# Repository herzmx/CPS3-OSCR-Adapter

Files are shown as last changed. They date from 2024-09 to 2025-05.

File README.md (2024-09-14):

# CPS3 SIMM/CARTRIDGE PORT ADAPTER for OSCR

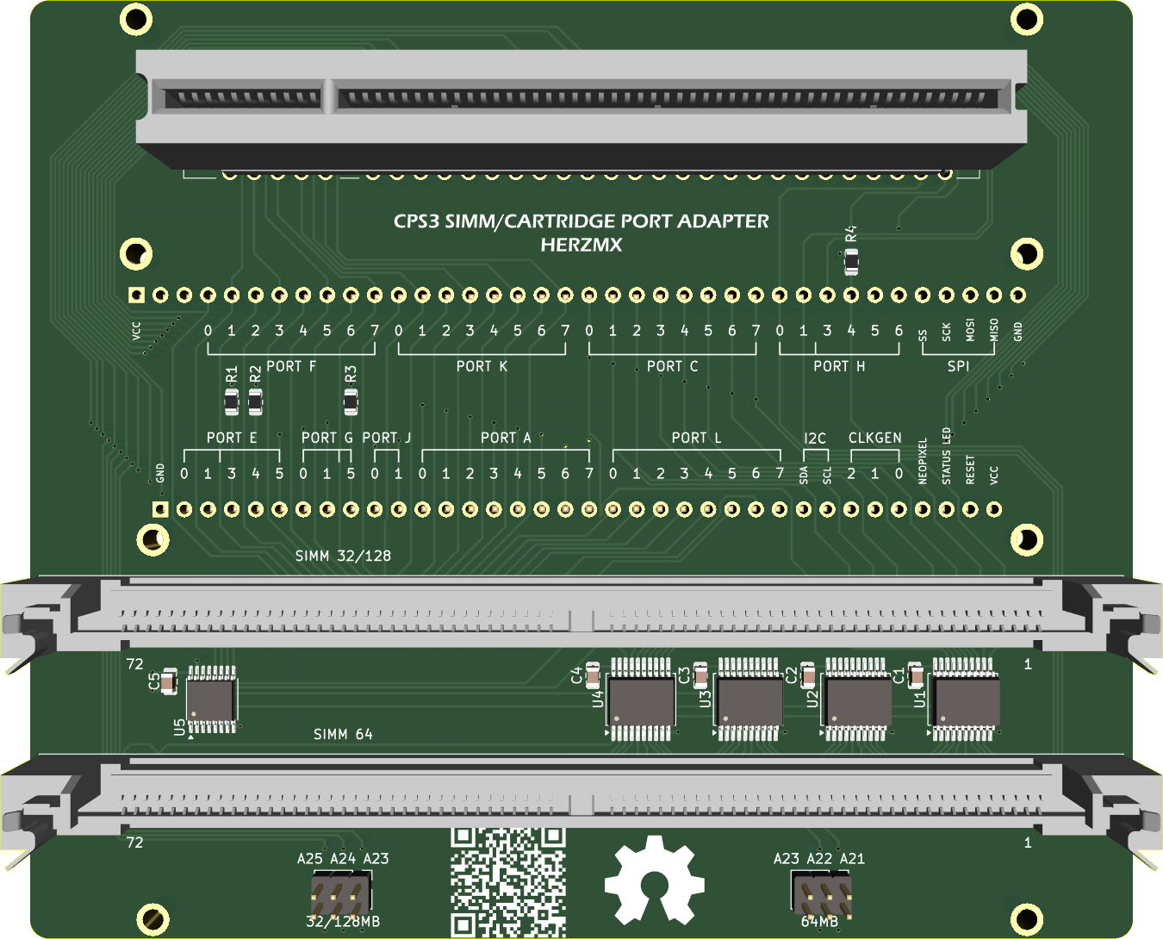
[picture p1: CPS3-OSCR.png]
system


The purpose of this adapter is to provide additional methods for reading and writing CP System III cartridges and SIMM memories, utilizing the excellent open-source project [Open Source Cartridge Reader (OSCR)](https://github.com/herzmx/cartreader/).

You can enable module uncomenting **ENABLE_CPS3**, **ENABLE_FLASH8** and **ENABLE_FLASH16** in Confing.h . While the R/W implementation in OSCR is not as fast as standard flash memory programmers, it allows you to dump and flash new data without needing to desolder the flash memories from the cartridge or SIMMs.

In this version, patches have been added to change the region and CD/NOCD options, based on documented dumps from MAME.

## Compatibility

### Cartridge

You can read and write the **BIOS** from a cartridge using Fujitsu MBM29F400TC (0x0423) or MBM29F400BC (0x0422) Flash ROMs.

If you flash or write a previously dumped BIOS, as documented in the MAME [cps3.cpp](https://github.com/mamedev/mame/blob/master/src/mame/capcom/cps3.cpp), the following patches can be applied:

- Region patch
- CD/NOCD patch

**Note:** This has only been tested on *Street Fighter III: 2nd Impact* and the *Ultra BIOS*. Use it at your own risk when working with live cartridges.

### SIMM's

You can read and write from 32/128Mb and 64Mb SIMMs using Fujitsu MBM29F016A (0x04AD) Flash ROMs. While CPS3 systems support multiple models of Flash ROMs, I have only tested with the Fujitsu model. Below is a list of Flash ROM models registered in the BIOS, meaning you cannot replace Flash ROMs without modifying the BIOS.

| MODEL | DataSheet | Physical Access |
|---|---|---|
| MXCI MX29F016 | YES | NO |
| SHARP LH28F016SU | YES | NO |
| INTEL 28F016SA | YES | NO |
| HITACHI HN98F1600T10  | NO | YES |

### 32/128Mb SIMMs

The SIMM is arranged as 2x8 bits across 4 banks, with each bank handling 4MB and accessing data in 16 bits. The adapter uses an LS139 to access each bank through addresses 21 and 22.

The dump is a complete 4MB/16MB file and matches with the set of files found inside the CD-ROM. For example, SIMM 3 in *Street Fighter III 2nd Impact* corresponds to files 30+31. You can compare or write data by joining these two files.

### 64Mb SIMMs

The SIMM is arranged as 4x8 bits and accesses data in 32 bits. The adapter uses an LS245 as a bus controller to access 16 bits at a time.

The dump is a complete 8MB file and matches with the set of files from the CD-ROM. For example, SIMM 1 in *Street Fighter III 2nd Impact* corresponds to file 10, so you can write this file directly.

## Disclaimer!!!

**I am not responsible for any damage to your CPS3 cartridges or SIMMs. At this time, it remains untested in live cartridges, so use it at your own risk!**

## License
<br />This work is licensed under a <a rel="license" href="http://creativecommons.org/licenses/by-sa/4.0/">Creative Commons Attribution-ShareAlike 4.0 International License</a>. You are able to copy and redistribute the material in any medium or format, as well as remix, transform, or build upon the material for any purpose (even commercial) - but you **must** give appropriate credit, provide a link to the license, and indicate if any changes were made.

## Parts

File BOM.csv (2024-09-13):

Designator | Mfr. No | Quantity | Description
C1-C5 | CC1206KRX7R9BB104 | 5 | 50V 100nF X7R ±10% 0805
J1,J2 | 5822030-3 or 5822021-4 | 2 | SIMM Socket | https://www.te.com/es/product-5822030-3.html | https://www.te.com/es/product-5822021-4.html
J3,J4 | 2.54-1*40P21MM | 2 | 2.54-1*40P21MM | https://www.lcsc.com/product-detail/Pin-Headers_BOOMELE-Boom-Precision-Elec-C51353_C51353.html
J5 | 5145154-1 | 1 | Cartridge socket | https://www.te.com/es/product-5145154-1.html
U1-U4 | SN74LS245DBR | 4 | Octal Bus Transceivers With 3-State Outputs | https://www.digikey.com.mx/es/products/detail/texas-instruments/SN74LS245DBR/1590463
U5 | SN74HCT139PWR | 1 | Dual 2-Line To 4-Line Decoders/Demultiplexers | https://www.digikey.com.mx/es/products/detail/texas-instruments/SN74HCT139PWR/390459

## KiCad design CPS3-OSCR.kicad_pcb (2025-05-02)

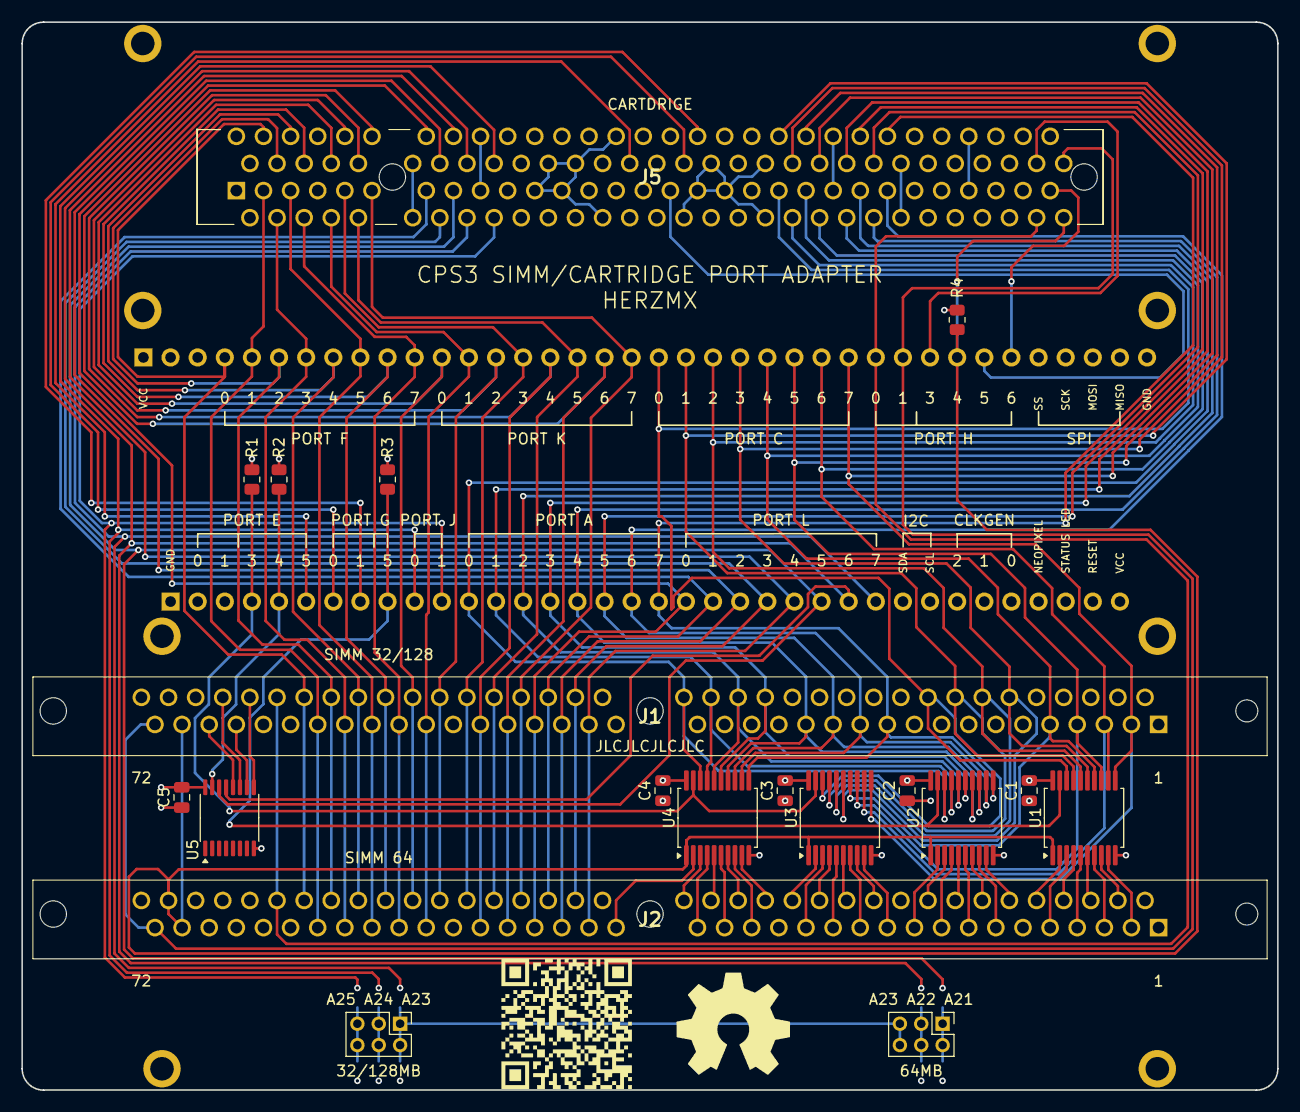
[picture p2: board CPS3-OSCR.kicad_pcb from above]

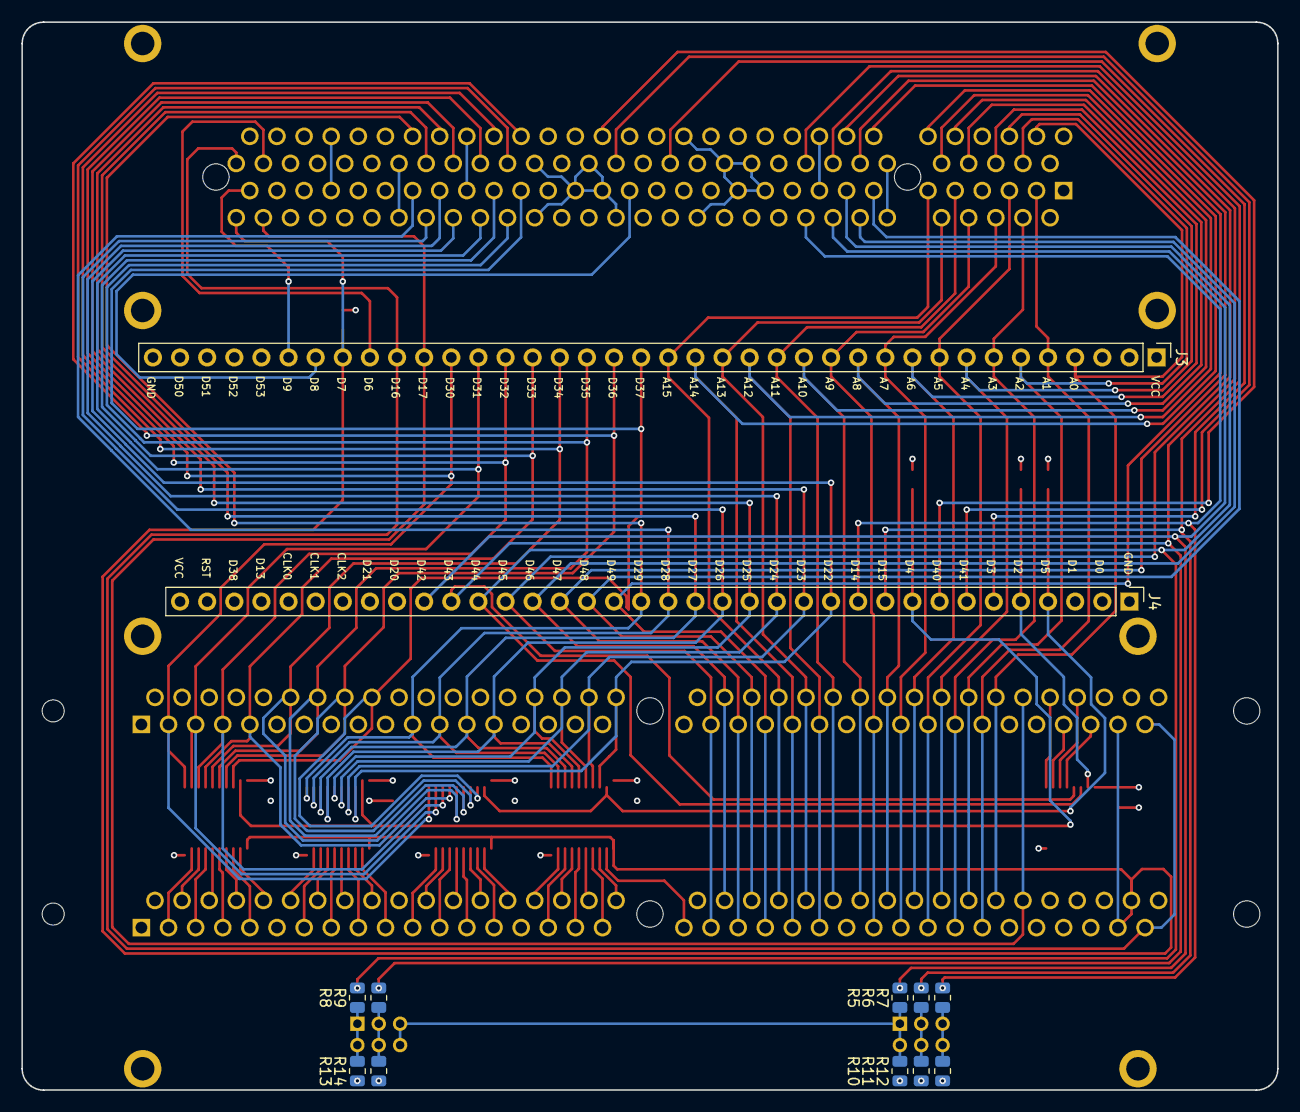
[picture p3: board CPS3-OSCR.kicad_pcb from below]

Board: 4 copper layers, 117.6 x 100.0 mm, 38 parts (12 on the bottom side), 97 nets.

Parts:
C1, C2, C3, C4, C5: 100nf; C_0805_2012Metric
J1: 128MB; 58220303
J2: 64MB; 58220303
J3: CART SLOT TOP ROW; PinHeader_1x38_P2.54mm_Vertical
J4: CART SLOT BOTTOM ROW; PinHeader_1x36_P2.54mm_Vertical
J5: 5145154-1; 51451541
J6, J7: Conn_02x03_Counter_Clockwise; PinHeader_2x03_P2.00mm_Vertical
M2_1, M2_2, M2_3, M2_4, M2_5, M2_5#2, M2_6: Screw_Terminal_01x01; MountingHole_2.2mm_M2_ISO7380_Pad
R1, R2, R3, R4: 10K; R_0805_2012Metric
R5, R6, R7, R8, R9: 1K; R_0805_2012Metric
R10, R11, R12, R13, R14: 2K; R_0805_2012Metric
U1, U2, U3, U4: 74LS245; SSOP-20_5.3x7.2mm_P0.65mm_.45
U5: 74HCT139; TSSOP-16_4.4x5mm_P0.65mm

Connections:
/A21R: J7.1, J7.2, R8.2, R13.2
/A22R: J7.3, J7.4, R9.2, R14.2
/A23R: J6.1, J6.2, J7.5, J7.6, R5.2, R10.2
/A24R: J6.3, J6.4, R6.2, R11.2
/A25R: J6.5, J6.6, R7.2, R12.2
/CEA: J1.64, U5.9 (O3)
/CEB: J1.65, U5.10 (O2)
/CEC: J1.66, U5.11 (O1)
/CED: J1.67, U5.12 (O0)
/IC1-D0: J2.37, U4.2 (A0)
/IC1-D1: J2.36, U4.3 (A1)
/IC1-D2: J2.35, U4.4 (A2)
/IC1-D3: J2.34, U4.5 (A3)
/IC1-D4: J2.33, U4.6 (A4)
/IC1-D5: J2.32, U4.7 (A5)
/IC1-D6: J2.31, U4.8 (A6)
/IC1-D7: J2.30, U4.9 (A7)
/IC2-D0: J2.28, U3.2 (A0)
/IC2-D1: J2.27, U3.3 (A1)
/IC2-D2: J2.26, U3.4 (A2)
/IC2-D3: J2.25, U3.5 (A3)
/IC2-D4: J2.24, U3.6 (A4)
/IC2-D5: J2.23, U3.7 (A5)
/IC2-D6: J2.22, U3.8 (A6)
/IC2-D7: J2.21, U3.9 (A7)
/IC3-D0: J2.19, U2.2 (A0)
/IC3-D1: J2.18, U2.3 (A1)
/IC3-D2: J2.17, U2.4 (A2)
/IC3-D3: J2.16, U2.5 (A3)
/IC3-D4: J2.15, U2.6 (A4)
/IC3-D5: J2.14, U2.7 (A5)
/IC3-D6: J2.13, U2.8 (A6)
/IC3-D7: J2.12, U2.9 (A7)
/IC4-D0: J2.10, U1.2 (A0)
/IC4-D1: J2.9, U1.3 (A1)
/IC4-D2: J2.8, U1.4 (A2)
/IC4-D3: J2.7, U1.5 (A3)
/IC4-D4: J2.6, U1.6 (A4)
/IC4-D5: J2.5, U1.7 (A5)
/IC4-D6: J2.4, U1.8 (A6)
/IC4-D7: J2.3, U1.9 (A7)
A0: J1.60, J2.60, J3.4 (A0), J5.B3 (116)
A1: J1.59, J2.59, J3.5 (A1), J5.A3 (115)
A2: J1.58, J2.58, J3.6 (A2), J5.B4 (114)
A3: J1.57, J2.57, J3.7 (A3), J5.A4 (113)
A4: J1.56, J2.56, J3.8 (A4), J5.B5 (112)
A5: J1.55, J2.55, J3.9 (A5), J5.A5 (111)
A6: J1.54, J2.54, J3.10 (A6), J5.B6 (110)
A7: J1.53, J2.53, J3.11 (A7), J5.A6 (109)
A8: J1.52, J2.52, J3.12 (A8), J5.B8 (106)
A9: J1.51, J2.51, J3.13 (A9), J5.A8 (105)
A10: J1.50, J2.50, J3.14 (A10), J5.B9 (104)
A11: J1.48, J2.48, J3.15 (A11), J5.A9 (103)
A12: J1.47, J2.47, J3.16 (A12), J5.B10 (102)
A13: J1.46, J2.46, J3.17 (A13), J5.A10 (101)
A14: J1.45, J2.45, J3.18 (A14), J5.B11 (100)
A15: J1.44, J2.44, J3.19 (A15), J5.A11 (99)
A16: J1.43, J2.43, J4.20 (D49), J5.B13 (96)
A17: J1.42, J2.42, J4.21 (D48), J5.A13 (95)
A18: J1.41, J2.41, J4.22 (D47), J5.B14 (94)
A19: J1.40, J2.40, J4.23 (D46), J5.A14 (93)
A20: J1.39, J2.39, J4.24 (D45), J5.B15 (92)
A21: J4.25 (D44), J5.A15 (91), R8.1, U5.14 (A0)
A22: J4.26 (D43), J5.B16 (90), R9.1, U5.13 (A1)
A23: J4.27 (D42), J5.A16 (89), R5.1
A24: J4.10 (D15), J5.B18 (86), R6.1
A25: J4.11 (D14), J5.A18 (85), R7.1
BYTE: J3.30 (D6), J5.B58 (6)
CE64LSB: J4.4 (D5), R1.2, U3.19 (CE), U4.19 (CE)
CE64MSB: J4.9 (D4), R3.2, U1.19 (CE), U2.19 (CE)
CE128: J4.5 (D2), R2.2, U5.15 (E)
CKIO_CPUC: J3.32 (D8), J5.A31 (59)
DQ0: J1.18, J3.20 (D37), J5.A39 (43), U1.18 (B0), U3.18 (B0)
DQ1: J1.16, J3.21 (D36), J5.B39 (44), U1.17 (B1), U3.17 (B1)
DQ2: J1.14, J3.22 (D35), J5.A40 (41), U1.16 (B2), U3.16 (B2)
DQ3: J1.12, J3.23 (D34), J5.B40 (42), U1.15 (B3), U3.15 (B3)
DQ4: J1.9, J3.24 (D33), J5.A41 (39), U1.14 (B4), U3.14 (B4)
DQ5: J1.7, J3.25 (D32), J5.B41 (40), U1.13 (B5), U3.13 (B5)
DQ6: J1.5, J3.26 (D31), J5.A42 (37), U1.12 (B6), U3.12 (B6)
DQ7: J1.3, J3.27 (D30), J5.B42 (38), U1.11 (B7), U3.11 (B7)
DQ8: J1.36, J4.12 (D22), J5.A44 (33), U2.18 (B0), U4.18 (B0)
DQ9: J1.34, J4.13 (D23), J5.B44 (34), U2.17 (B1), U4.17 (B1)
DQ10: J1.32, J4.14 (D24), J5.A45 (31), U2.16 (B2), U4.16 (B2)
DQ11: J1.30, J4.15 (D25), J5.B45 (32), U2.15 (B3), U4.15 (B3)
DQ12: J1.27, J4.16 (D26), J5.A46 (29), U2.14 (B4), U4.14 (B4)
DQ13: J1.25, J4.17 (D27), J5.B46 (30), U2.13 (B5), U4.13 (B5)
DQ14: J1.23, J4.18 (D28), J5.A47 (27), U2.12 (B6), U4.12 (B6)
DQ15: J1.21, J4.19 (D29), J5.B47 (28), U2.11 (B7), U4.11 (B7)
GND: C1.1, C2.1, C3.1, C4.1, C5.1, J1.11, J1.20, J1.29, J1.49, J1.61, J1.63, J1.68, J2.11, J2.20, J2.29, J2.49, J2.61, J2.63, J2.67, J2.68, J3.38 (GND), J4.1 (GND), J5.A7 (107), J5.A12 (97), J5.A17 (87), J5.A21 (79), J5.A23 (75), J5.A26 (69), J5.A32 (57), J5.A33 (55), J5.A35 (51), J5.A38 (45), J5.A43 (35), J5.A48 (25), J5.A53 (15), J5.B7 (108), J5.B12 (98), J5.B17 (88), J5.B22 (78), J5.B24 (74), J5.B27 (68), J5.B31 (60), J5.B34 (54), J5.B38 (46), J5.B43 (36), J5.B48 (26), J5.B53 (16), M2_1.1, M2_2.1, M2_5.1, M2_5#2.1, M2_6.1, R10.1, R11.1, R12.1, R13.1, R14.1, U1.10 (GND), U2.10 (GND), U3.10 (GND), U4.10 (GND), U5.8 (GND)
OE: J1.71, J2.71, J3.29 (D16), J5.B60 (2)
RST: J1.62, J2.62, J3.28 (D17), J5.A58 (5)
VCC: C1.2, C2.2, C3.2, C4.2, C5.2, J1.1, J1.2, J2.1, J2.2, J3.1 (VCC), J4.36 (VCC), J5.A1 (119), J5.A2 (117), J5.B1 (120), J5.B2 (118), R1.1, R2.1, R3.1, R4.1, U1.20 (VCC), U2.20 (VCC), U3.20 (VCC), U4.20 (VCC), U5.16 (VCC)
WAIT_CPUC: J4.6 (D3), J5.B28 (66)
WE: J1.69, J2.69, J2.70, J3.31 (D7), J5.A60 (1), R4.2, U1.1 (A->B), U2.1 (A->B), U3.1 (A->B), U4.1 (A->B)
~CER_CST: J3.33 (D9), J5.A59 (3)
~RST_CPUC: J4.8 (D40), J5.B33 (56)
~STBY_WD: J4.7 (D41), J5.B32 (58)

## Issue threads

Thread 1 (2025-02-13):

R1-R4 missing from BOM

sh00tthec0re, 2025-02-13:
What part should be populated for R1, R2, R3 and R4? Those were added to the Gerbers in the most recent update, but they aren't in the BOM.

herzmx, 2025-02-13:
10K it's pull up to be sure of levels

herzmx, 2025-02-14:
Fixed with bafec26

Closed 2025-02-14.

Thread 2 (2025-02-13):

Which cartridge ports on the OSCR does the CPS3 adapter plug into?

sh00tthec0re, 2025-02-13:
Can you clarify which cartridge ports on the OSCR your CPS3 adapter is supposed to plug into?  I have a newly-built CPS3 adapter along with a OSCR Hardware Version 5 Revision 5. None of the pin headers on the CPS3 adapter seem to line up with cart ports on the OSCR without leaving pins outside of the port.

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

herzmx, 2025-02-13:
Replace six slot adapter by cps3 adapter

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

sh00tthec0re, 2025-02-14:
Got it - thank you!  I purchased a preassembled OSCR specifically for rewriting CPS3 carts and wasn't familiar with how it assembled together internally.  I appreciate your information.

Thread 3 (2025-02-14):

General user question

dangermousehouse, 2025-02-14:
Hi, thank you so much for creating this awesome project, tonnes of fun!

Have assembled and programed OSCR + CPS3 top board, works but not exactly as expected. CPS3 security carts read the wrong flash chip ID, cannot erase and and other strangeness. Currently I have the board set for 3v (manual switch) - is 3v the correct voltage for the CPS3 security cart?

herzmx, 2025-02-14:
Chance to 5V

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

dangermousehouse, 2025-02-23:
Thank you, setting switch to +5v resolved issue, works as expected.

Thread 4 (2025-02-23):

CPS3 Carts Read Fine But Won’t Erase or Rewrite

sh00tthec0re, 2025-02-23:
I’ve assembled the adapter and updated the Arduino firmware with the CPS3 code. I’ve tested it with two carts, and although both carts will Read and dump correctly, neither cart will Erase or Write a new file successfully.

The Erase operation says “Please Wait” and never proceeds.

The Write operation does advance the progress bar but at the end, it displays a mismatch error and the contents of the flash are unchanged.

Both carts are using Fujitsu 29F400TA flash. My OSCR is the latest revision that doesn’t have a switch for 3.3V / 5.0V.

Any suggestions on what I should do to diagnose and fix this problem?

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

dangermousehouse, 2025-02-23:
I could not get OSCR auto voltage selection to work for me either. It would sorta-kinda work but throw up all kinds of weird errors (reading incorrect flash ID, unable to erase etc)
Eventually I built HW5v4 with a hardware voltage switch - has worked perfectly ever since.

sh00tthec0re, 2025-02-23:
I figured out the problem.  The Voltage Selector defaults to 3.3V and the firmware needs to tell it to raise the voltage to 5.0V.  Adding these three lines of code to the FLASH_CPS3.ino file at the beginning of the setup_CPS3 function fixed it:
  #if defined(ENABLE_VSELECT)
    setVoltage(VOLTS_SET_5V);
  #endif

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

herzmx, 2025-02-23:
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

Thanks, that's good news, I'll add it to the code, I don't have the selector and sorry I didn't see the issue in time.
Thanks also for the effort to test this project!!!

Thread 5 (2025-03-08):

Feature Request: SIMM Integrity Check?

lordviceroy, 2025-03-08:
First, I want to say thanks for putting this together and releasing it as open source. Between being able to reflash the BIOS without soldering, to region switching and BIOS dumping, this device is a huge benefit to CPS3 maintenance and preservation.

One thing that remains particularly frustrating is debugging issues with Capcom SIMM modules. Specifically, the modules using Fujitsu flash chips are known to frequently fail, causing write errors and various other problems. Capcom's error codes also don't seem particularly useful, and I'm not aware of an efficient way to debug flash errors other than manually desoldering chips and throwing them into a programmer.

Would it be possible to extend the OSCR's functionality to perform read and write tests on a SIMM modules flash chips and provide meaningful error messaging to help people identify and replace defective flash?

Thanks for your consideration!

herzmx, 2025-03-10:
Hi @lordviceroy,

That’s definitely on my task list! I’m still deciding whether to include it in the OSCR firmware or handle it with an external script due to memory limitations.

It’s possible to determine which ICs are bad dumping and compare them, but we need write proper documentation of the specific IC locations.

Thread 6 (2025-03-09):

Flash won't erase or rerpogram if Security Protect is enabled

sh00tthec0re, 2025-03-09:
I recently had a CPS3 cart with Darksoft SuperBIOS installed sent to me for updating with the UltraBIOS.  The cart has the Capcom CPU.

The cart wouldn't Erase or Program using the OSCR and CPS3 adapter - both functions would hang indefinitely.
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

I desoldered the flash from the cart PCB, loaded it into my Dataman programmer, and successfully executed the Erase operation there.  I noticed in the log that it Unprotected Sectors on the flash chip.
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

After the Dataman unprotected and erased the flash, I resoldered it back to the cart PCB and the OSCR was now able to work with it.  I successfully tested several Erase and Reprogram operations.
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

Anyway, I wanted to let you know that currently the OSCR CPS3 firmware doesn't currently erase or program a cart if Security Protection is enabled on the flash chip.  Hopefully the firmware can be updated to handle this.

lordviceroy, 2025-08-16:
Is it possible for the OSCR to detect when the protection bit is set to true and show an error to the user?

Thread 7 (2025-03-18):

fix BOM

djanice1980, 2025-03-18:
The caps might be the wrong part number if you are wanting people to purchase 0805.

CC0805KRX7R9BB104

instead of

CC1206KRX7R9BB104

I ordered based off your BOM and realized it must be a typo.

herzmx, 2025-03-18:
Fixed with  f1a3f5a

Closed 2025-03-18.

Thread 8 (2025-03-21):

Part number for 2x3 header on OSCR Adapter

djanice1980, 2025-03-21:
Not sure where to send you messages so I apologize if this is not a good place.

I was just wondering what the part number is for the 2x3 pin headers.  I purchased 2.51mm spacing and they are obviously not correct.

Also noticed that you are only using 1x3 for the wires when doing the SIMM programming - what are the other 3 pins for?

herzmx, 2025-03-21:
It's a 2x03 2.00mm connector. All the design footprints are in KiCAD, so don't worry you can reach out here or on Twitter.

Using a 2x03 connector provides better mechanic stability. The complete documentation, including instructions for creating the communication cable, is still pending, anyway his is only required for the Nor Open SIMM, and at the moment, I'm busy with office work, reviewing instability issues with the 128MB NOS it's still pending too...

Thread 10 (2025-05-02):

SIMM's orientation

scrap-a, 2025-05-02:
Thank you for designing and sharing this excellent device.
Reading and writing to the cartridge work fine, but there seems to be an issue with reading and writing to the SIMM.

Is the SIMM orientation described in README.md incorrect?
Based on the orientation of the protrusion that fits into the SIMM hole, it appears to be upward-facing.
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

I tested both upward and downward orientations, and the downward orientation allowed access to the SIMM.
In the following image, the left side shows the downward orientation, and the right side shows the upward orientation. The silkscreen also seems to fit the upward orientation.
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
This following image shows successful SIMM access with the downward orientation.
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

Which orientation is correct, upward or downward?

Additionally, I have some concerns about the software, but I will raise those in a separate thread as they are distinct issues.

herzmx, 2025-05-02:
Thanks for feedback im still using model of 5822021-4, thats works too...
Fix with https://github.com/herzmx/CPS3-OSCR-Adapter/commit/90845db930247e1c186867d90eb983c452c139a5

scrap-a, 2025-05-02:
Oh, sorry.
Was it the difference between "5822021-3" and "5822021-4"?
It would be helpful if it were clear which orientation to use for each case.
Thank you for updating the image and closing the issue.

herzmx, 2025-05-02:
Pin 1 match with restriction on socket.

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

herzmx, 2025-05-02:
Update 5822030-3 it's the replacement in CPS3 PCB...

scrap-a, 2025-05-03:
Thanks for the update.
I think the only difference between “5822021-3” and “5822021-4” is the direction in which the SIMM is pointed.
So, I don't think it is necessary, but if you ever need to test with “5822021-3”, please contact me.

scrap-a, 2025-05-03:
I misunderstood.
I'm using "5822021-4".

Closed 2025-05-02.

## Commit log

2024-09-12 Release commit
    [CPS3-OSCR.kicad_pcb, CPS3-OSCR.kicad_sch]
2024-09-12 Add BOM
    [BOM.csv]
2024-09-13 Update BOM
    [BOM.csv]
2025-05-02 Fix 5822030-3 model orientation
    [CPS3-OSCR.kicad_pcb]
